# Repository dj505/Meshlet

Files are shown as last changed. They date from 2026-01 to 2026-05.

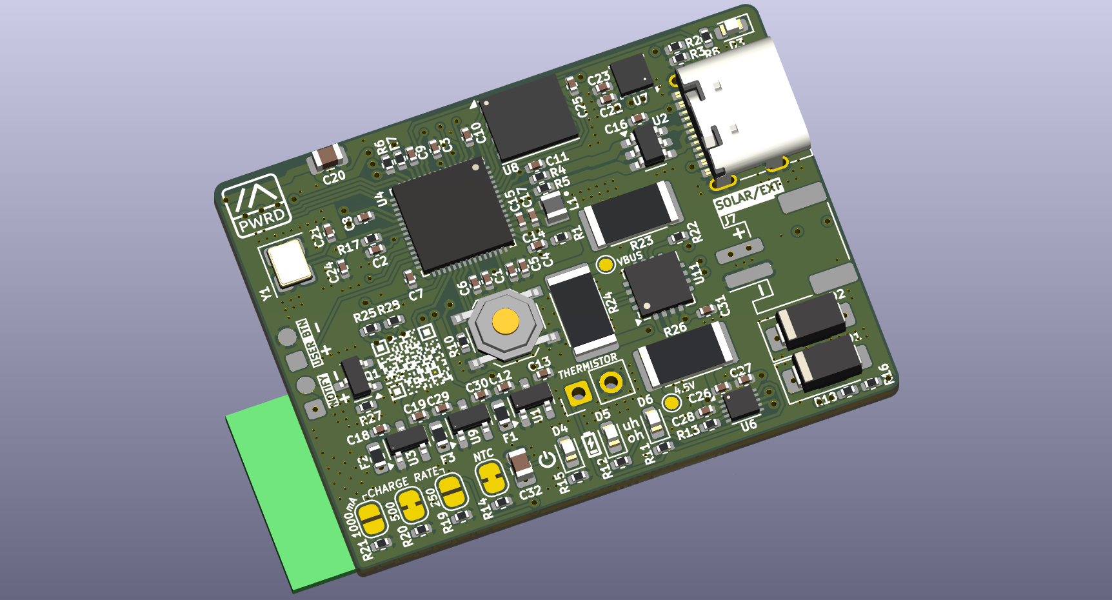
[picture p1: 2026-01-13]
docs/assets/1.png

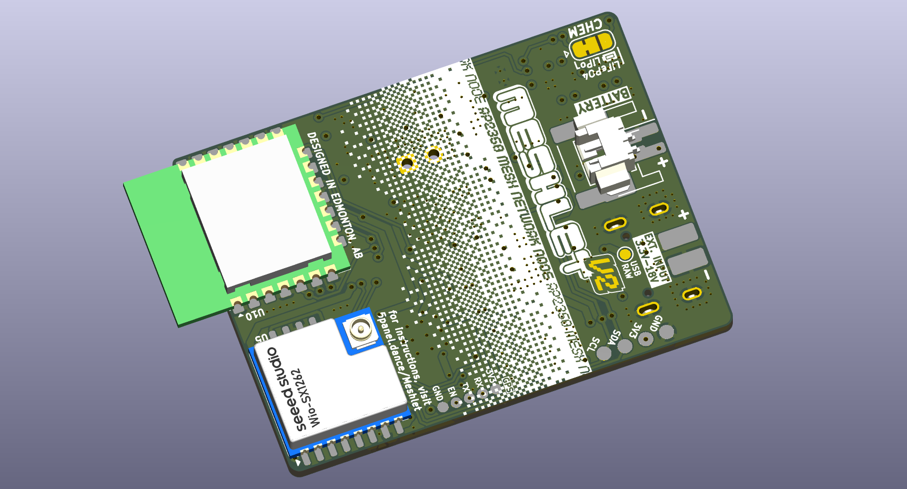
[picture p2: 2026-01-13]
docs/assets/2.png

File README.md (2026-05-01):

# [Meshlet V2](https://5panel.dance/Meshlet)

Meshlet is an open-source and feature-packed LoRa mesh network node, designed to be compatible (but not affiliated) with the Meshtastic® project. It's made to be deployed just about anywhere you want it to be - you can plug in a solar panel and set it up outside, turn it into a pocketable every-day-carry node, wire it up to your car as a mobile repeater, or even just leave it on a windowsill attached to a BBS script/Meshsense/etc. 

**Table of Contents**
1. [Features](#features)
2. [Project Sponsor](#project-sponsor)
3. [Real World Testing](#real-world-testing)
5. [Meshlet Docs](#meshlet-docs)

## Features
Features include, but are not limited to...
- USB C, with configurable charge rate limit (250mA, 500mA, 1A)
- LiPo/LiIon and LiFePo4 support
- ESD/TVS protection on the USB port
- Solar input (as well as constant DC input) from 3.3V to 18V, tolerant up to 25V
  - Flexible wiring methods, with dedicated JST PH footprints as well as pads to directly solder wires to!
  - Tested & working with as little as a cheap 80mm 5v solar panel, on an overcast Canadian winter day!
  - Unlike many boards that need a manual reset after too little sunlight drains the battery, the Meshlet should recover on its own!
- Smart power path management, thanks to the BQ25185. No need to worry about unnecessarily cycling the battery!
- JST 2.0 and Picoblade 1.5mm battery connector footprints, to hopefully fit whatever LiPos you've got laying around
- Low operating power, measuring as low as 2.8mA idle current draw (without WiFi)
- Active current/voltage monitoring and reporting on 3 channels over the mesh, via INA3221
  - Ch. 1: Battery
  - Ch. 2: USB & external power
  - Ch. 3: BQ25185 regulated battery output
- Up to 8MB onboard flash
- WIO-SX1262 LoRa radio
- BME280 temperature/humidity/barometric pressure sensor
- I2C expansion port
- Dedicated 3.3V regulators for all major components, each with its own self-resetting fuse, to ensure stable power
- "External notification" header for a MOSFET-driven 3.3V buzzer, LED, vibration motor, etc
- Raspberry Pi RM2 for optional WiFi (and Bluetooth, whenever the firmware supports it)
- Total footprint size of ~42*32mm, less than half the size of a credit card!

## Project Sponsor
This project is sponsored by [PCBWay](https://pcbway.com)! Absolutely massive thank you to them for helping make these projects possible for me.

If you're interested in DIY electronics, I'm sure you're familiar with the name. PCBWay is a manufacturing company specializing in circuit boards, but they also offer services for SMT assembly, CNC milling, 3D printing, sheet metal fabrication, and injection molding! They can manufacture all of the parts for your hobby project, in one convenient place, with fine-grained control over the entire manufacturing process.

I relied pretty heavily on their PCB manufacturing and SMT assembly services to get the final revision of the Meshlet project built & tested. In my past experience, their boards always come out beautiful and pretty near perfect, and these ones are no exception. Their engineers were in contact with me from start to finish, making sure that everything was correct and to spec throughout each step of the process. They sourced all of the parts based on the BOM I provided, ensured that each pick lined up with what I needed, and even sent confirmation photos before the assembly process to ensure that every part was placed & oriented properly. When I mistakenly selected two parts to fit a single footprint, they agreed with my request to ship me the extra parts that I had them order alongside the PCBs, for me to solder by hand if needed after I receive them!

Sponsors like this make a huge difference in allowing me to continue testing & iterating on projects like this one. Without this opportunity, it likely would have stopped at the first revision prototype! Thanks again to PCBWay for reaching out and organizing this opportunity. Please [check them out](https://pcbway.com), and definitely consider using their services for your next project! 

## Real World Testing
Meshlet has been tested in a variety of real-world use cases thus far, including...
- **Building side solar repeater:** An early Meshlet V2 revision (1.0) installed inside a weatherproof box, with a 5V solar panel and 3000mAh LiPo, in late winter conditions. Runs Meshtastic in CLIENT_BASE mode. Uptime as of writing is roughly a month, with zero resets or brownouts. Battery life has not dropped below 40%. Average draw is 28-32mA, plus an extra 8-12mA due to a secondary nRF52 MeshCore repeater node being powered via the 3v3 peripheral pins.
- **Cheap garden light repeater:** A latest revision Meshlet V2 (1.1) installed inside a cheap solar garden light from Home Depot. Solar panel has been wired directly to the solar input. Powered by two 1000mAh parallel LiFePO4 18500 batteries that came with the light. Has not yet dropped below 50% in 1 week of testing. Runs MeshCore, as a repeater.
- **Handheld unit:** An early revision Meshlet V2 (1.0) in a custom 3D printed case, with an I2C OLED and M5Stack CardKB soldered to the I2C breakout. Powered by a 3000mAh battery. Running Meshtastic. Has not yet undergone extensive testing, but showed promise with a battery life lasting at least 3 days with the CLIENT_MUTE role.
- **Bench testing:** Early revision Meshlet V2 (1.0) in the plastic case from a Heltec T114, powered by a recycled 1000mAh vape battery. Has undergone testing with several different solar panels (4V-7V), DC power supplies (5V-12V), charge rates, and I2C peripherals. Has been able to handle everything I've thrown at it so far. Survived having both a solar panel and a battery being plugged in with the incorrect polarity on separate occasions.

## Meshlet Docs
Assembly notes, firmware, and usage notes can all be found on [the Meshlet webpage.](https://www.5panel.dance/Meshlet/)

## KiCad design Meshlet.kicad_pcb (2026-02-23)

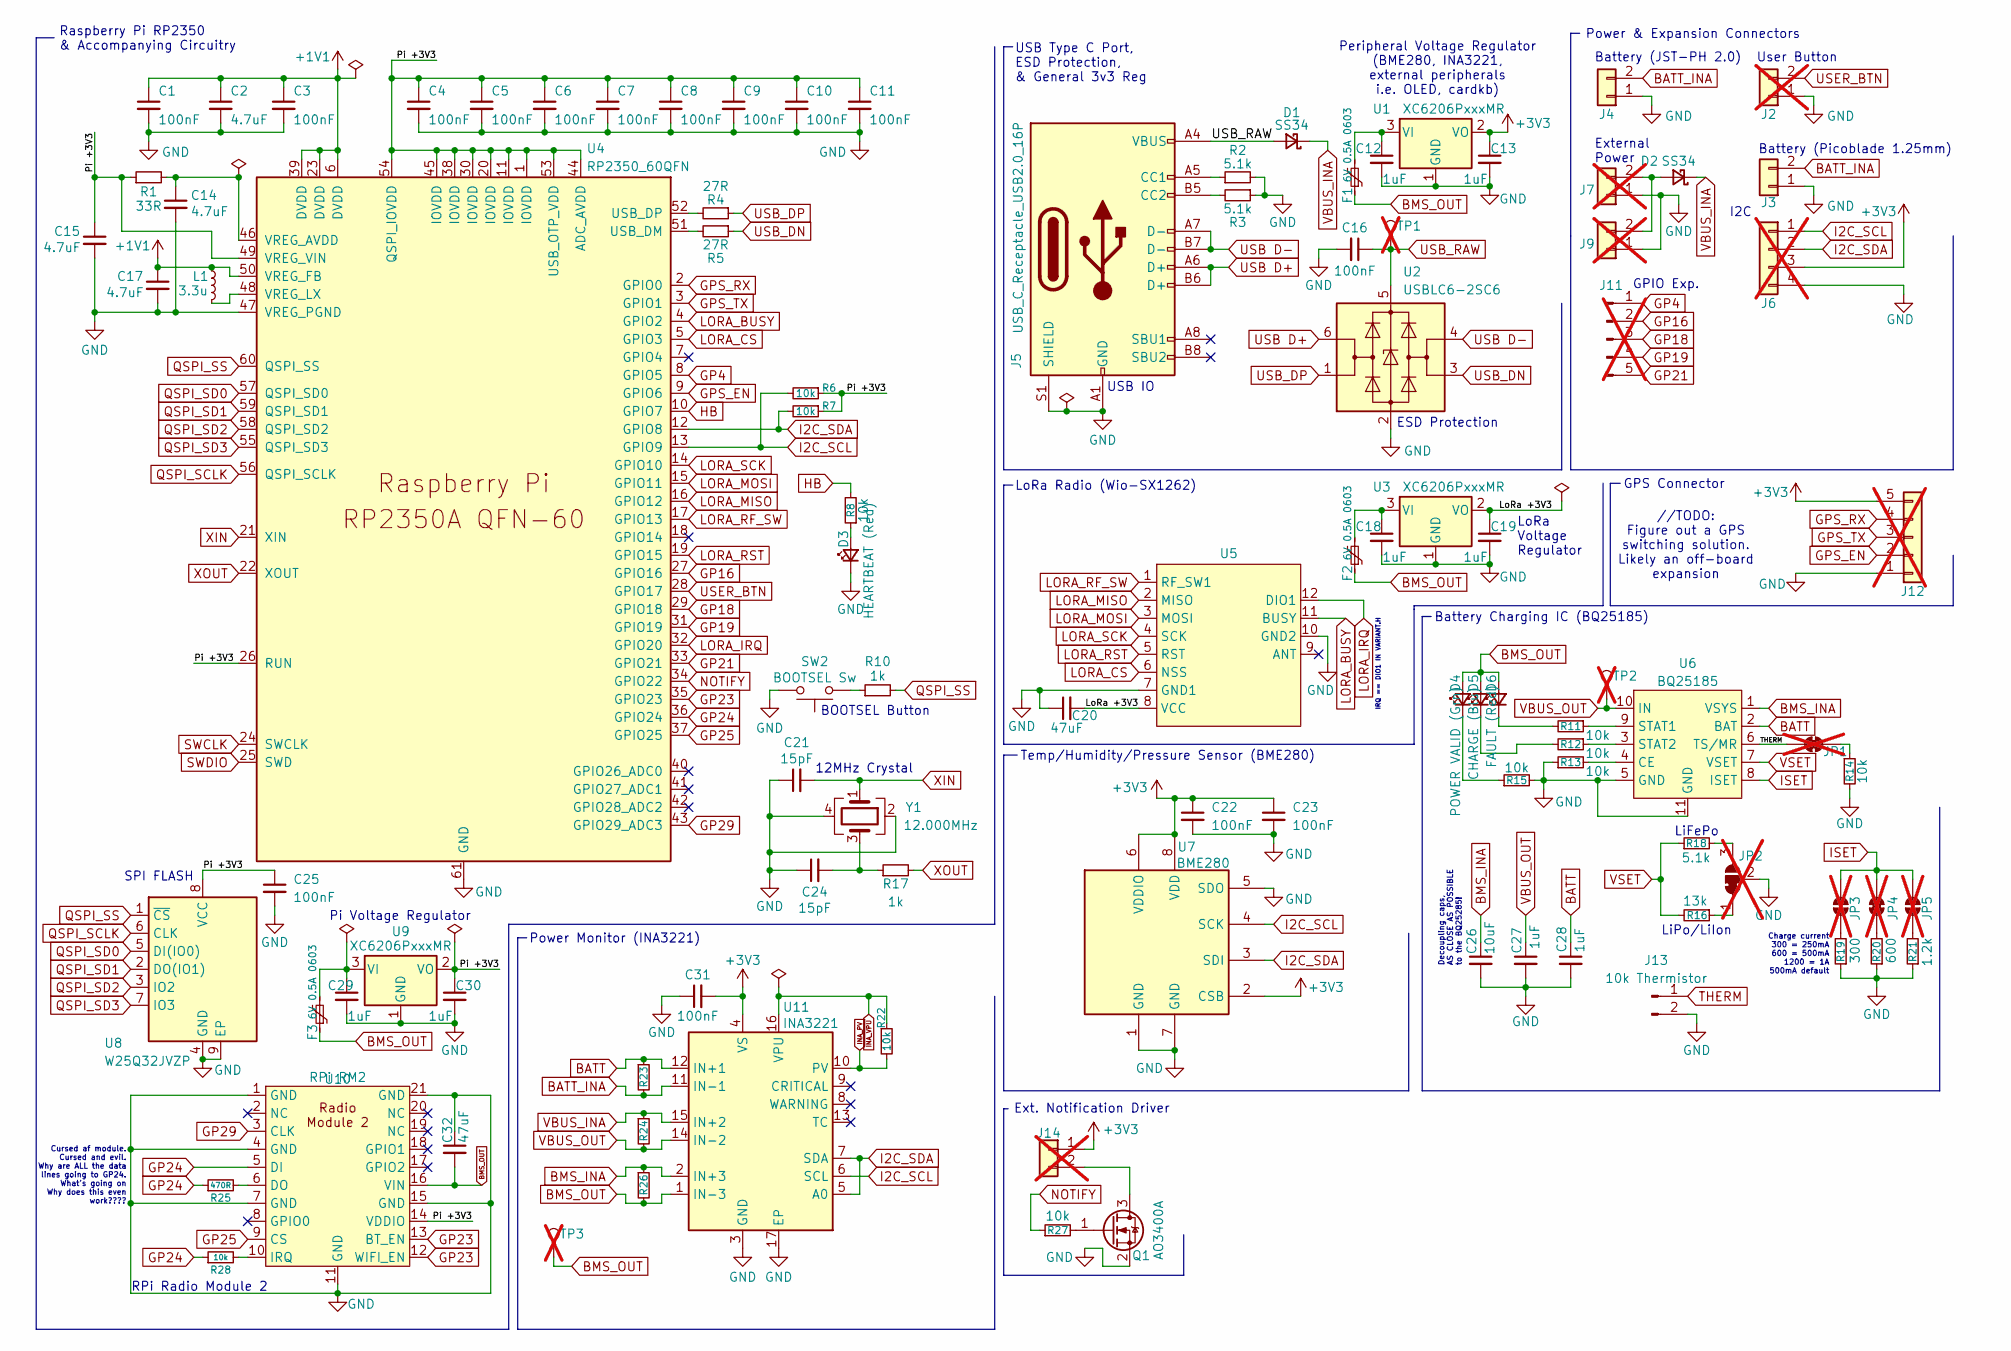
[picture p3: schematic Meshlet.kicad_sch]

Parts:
C1, C3, C4, C5, C6, C7, C8, C9, C10, C11, C16, C22, C23, C25, C31: 100nF; C_0402_1005Metric; LCSC C1525
C2, C14: 4.7uF; C_0402_1005Metric; LCSC C23733
C12, C13, C18, C19, C29, C30: 1uF; C_0402_1005Metric; LCSC C52923
C15, C17: 4.7uF; C_0402_1005Metric_small_pads; LCSC C23733
C20, C32: 47uF; C_0805_2012Metric; LCSC C16780
C21, C24: 15pF; C_0402_1005Metric; LCSC C1548
C26: 10uF; C_0402_1005Metric; LCSC C105226
C27, C28: 1uF; C_0402_1005Metric; LCSC C105226
D1, D2: SS34; D_SMA; LCSC C8678
D3: HEARTBEAT (Red); LED_0603_1608Metric; LCSC C2290
D4: POWER VALID (Grn); LED_0603_1608Metric; LCSC C2290
D5: CHARGE (Blu); LED_0603_1608Metric; LCSC C2290
D6: FAULT (Red); LED_0603_1608Metric; LCSC C2286
F1, F2, F3: 6V 0.5A 0603; Fuse_0603_1608Metric; LCSC C69679
J2: User Btn Header; PinHeader_1x02_P2.00mm_Vertical; not fitted
J3: Batt. Header (Picoblade 1.25); Molex_PicoBlade_53261-0271_1x02-1MP_P1.25mm_Horizontal; LCSC C177225
J4: Batt. Header (JST-PH 2.0); JST_PH_S2B-PH-SM4-TB_1x02-1MP_P2.00mm_Horizontal; LCSC C47647
J5: USB_C_Receptacle_USB2.0_16P; USB_C_Receptacle_G-Switch_GT-USB-7010ASV; LCSC C393939
J6: I2C Header; PinHeader_1x04_P2.00mm_Vertical; not fitted
J7: Ext. Power Header; JST_PH_S2B-PH-SM4-TB_1x02-1MP_P2.00mm_Horizontal; LCSC C27910; not fitted
J9: Ext. Power Header; PinHeader_1x02_P2.54mm_Vertical; not fitted
J11: GPIO Exp.; PinHeader_1x05_P2.00mm_Vertical; not fitted
J12: GPS Header; PinHeader_1x05_P1.27mm_Vertical; not fitted
J13: 10k Thermistor; PinHeader_1x02_P2.54mm_Vertical
J14: Ext. Notif. Header; PinHeader_1x02_P2.00mm_Vertical; not fitted
JP1: TS; SolderJumper-2_P1.3mm_Bridged_RoundedPad1.0x1.5mm; not fitted
JP2: Chemistry Select; SolderJumper-3_P1.3mm_Bridged12_RoundedPad1.0x1.5mm; not fitted
JP3: 250mA Charge; SolderJumper-2_P1.3mm_Open_RoundedPad1.0x1.5mm; not fitted
JP4: 500mA Charge; SolderJumper-2_P1.3mm_Bridged_RoundedPad1.0x1.5mm; not fitted
JP5: 1A Charge; SolderJumper-2_P1.3mm_Open_RoundedPad1.0x1.5mm; not fitted
L1: 3.3u; L_pol_2016; LCSC C42411119
Q1: AO3400A; SOT-23; LCSC C20917
R1: 33R; R_0402_1005Metric; LCSC C25105
R2, R3, R18: 5.1k; R_0402_1005Metric; LCSC C25905
R4, R5: 27R; R_0402_1005Metric; LCSC C25100
R6, R7, R8, R11, R12, R13, R14, R15, R22, R27, R28: 10k; R_0402_1005Metric; LCSC C25744
R10, R17: 1k; R_0402_1005Metric; LCSC C11702
R16: 13k; R_0402_1005Metric; LCSC C25754
R19: 300; R_0402_1005Metric; LCSC C25102
R20: 600; R_0402_1005Metric; LCSC C25126
R21: 1.2k; R_0402_1005Metric; LCSC C25862
R23, R24, R26: PA2512FKF7W0R01E; R_2512_6332Metric; LCSC C875838
R25: 470R; R_0402_1005Metric; LCSC C25117
SW2: BOOTSEL Sw; SW_Push_1P1T_XKB_TS-1187A; LCSC C318884
TP1, TP2, TP3: TestPoint; TestPoint_Pad_D1.0mm; not fitted
U1, U3, U9: XC6206PxxxMR; SOT-23-3; LCSC C5446
U2: USBLC6-2SC6; SOT-23-6; LCSC C2687116
U4: RP2350_60QFN; RP2350-QFN-60-1EP_7x7_P0.4mm_EP3.4x3.4mm_ThermalVias; LCSC C42411118
U5: Wio-SX1262
U6: BQ25185; Texas_DLH0010A_WSON-10-1EP_2.2x2mm_P0.4mm_EP0.9x1.5mm_Therm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; LCSC C19725033
U7: BME280; Bosch_LGA-8_2.5x2.5mm_P0.65mm_ClockwisePinNumbering; LCSC C92489
U8: W25Q32JVZP; WSON-8-1EP_6x5mm_P1.27mm_EP3.4x4.3mm; LCSC C2940197
U10: RPi RM2; Radio Module 2
U11: INA3221; Texas_RGV0016A_VQFN-16-1EP_4x4mm_P0.65mm_EP2.1x2.1mm; LCSC C181255
Y1: 12.000MHz; Crystal_SMD_3225-4Pin_3.2x2.5mm; LCSC C20625731

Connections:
+1V1: C1.1, C2.1, C3.1, C17.1, L1.1, U4.6 (DVDD), U4.23 (DVDD), U4.39 (DVDD), U4.50 (VREG_FB)
+3V3: C13.1, C22.1, C23.1, C31.2, J6.3, J12.5, J14.1, U1.2 (VO), U7.2 (CSB), U7.6 (VDDIO), U7.8 (VDD), U11.4 (VS)
/LoRa +3V3: C19.1, C20.2, U3.2 (VO), U5.8 (VCC)
/Pi +3V3: C4.1, C5.1, C6.1, C7.1, C8.1, C9.1, C10.1, C11.1, C15.1, C25.1, C30.1, R1.1, R6.1, R7.1, U4.1 (IOVDD), U4.11 (IOVDD), U4.20 (IOVDD), U4.26 (RUN), U4.30 (IOVDD), U4.38 (IOVDD), U4.44 (ADC_AVDD), U4.45 (IOVDD), U4.49 (VREG_VIN), U4.53 (USB_OTP_VDD), U4.54 (QSPI_IOVDD), U8.8 (VCC), U9.2 (VO), U10.14 (VDDIO)
BATT: C28.1, R23.1, U6.2 (BAT), U11.12 (IN+1)
BATT_INA: J3.2, J4.2, R23.2, U11.11 (IN-1)
BMS_INA: C26.1, R26.1, U6.1 (VSYS), U11.2 (IN+3)
BMS_OUT: C32.2, D4.2 (A), D5.2 (A), D6.2 (A), F1.1, F2.1, F3.1, R26.2, TP3.1, U10.16 (VIN), U11.1 (IN-3)
GND: C1.2, C2.2, C3.2, C4.2, C5.2, C6.2, C7.2, C8.2, C9.2, C10.2, C11.2, C12.2, C13.2, C14.2, C15.2, C16.2, C17.2, C18.2, C19.2, C20.1, C21.1, C22.2, C23.2, C24.1, C25.2, C26.2, C27.2, C28.2, C29.2, C30.2, C31.1, C32.1, D3.1 (K), J2.1, J3.1, J4.1, J5.A1 (GND), J5.A12 (GND), J5.B1 (GND), J5.B12 (GND), J5.S1 (SHIELD), J6.4, J7.1, J9.1, J12.1, J13.2, JP2.2 (C), Q1.2 (S), R2.2, R3.1, R13.1, R14.2, R15.2, R19.1, R20.1, R21.1, SW2.2, U1.1 (GND), U2.2 (GND), U3.1 (GND), U4.47 (VREG_PGND), U4.61 (GND), U5.7 (GND1), U5.10 (GND2), U6.5 (GND), U6.11 (GND), U7.1 (GND), U7.5 (SDO), U7.7 (GND), U8.4 (GND), U8.9 (EP), U9.1 (GND), U10.1 (GND), U10.4 (GND), U10.7 (GND), U10.11 (GND), U10.15 (GND), U10.21 (GND), U11.3 (GND), U11.17 (EP), Y1.2, Y1.4
GP4: J11.1, U4.8 (GPIO5)
GP16: J11.2, U4.27 (GPIO16)
GP18: J11.3, U4.29 (GPIO18)
GP19: J11.4, U4.31 (GPIO19)
GP21: J11.5, U4.33 (GPIO21)
GP23: U4.35 (GPIO23), U10.12 (WIFI_EN), U10.13 (BT_EN)
GP24: R25.1, R28.1, U4.36 (GPIO24), U10.5 (DI)
GP25: U4.37 (GPIO25), U10.9 (CS)
GP29: U4.43 (GPIO29_ADC3), U10.3 (CLK)
GPS_EN: J12.2, U4.9 (GPIO6)
GPS_RX: J12.4, U4.2 (GPIO0)
GPS_TX: J12.3, U4.3 (GPIO1)
HB: R8.2, U4.10 (GPIO7)
I2C_SCL: J6.1, R6.2, U4.13 (GPIO9), U7.4 (SCK), U11.6 (SCL)
I2C_SDA: J6.2, R7.2, U4.12 (GPIO8), U7.3 (SDI), U11.5 (A0), U11.7 (SDA)
INA_PV: R22.2, U11.10 (PV)
INA_VPU: R22.1, U11.16 (VPU)
ISET: JP3.2 (B), JP4.2 (B), JP5.2 (B), U6.8 (ISET)
LORA_BUSY: U4.4 (GPIO2), U5.11 (BUSY)
LORA_CS: U4.5 (GPIO3), U5.6 (NSS)
LORA_IRQ: U4.32 (GPIO20), U5.12 (DIO1)
LORA_MISO: U4.16 (GPIO12), U5.2 (MISO)
LORA_MOSI: U4.15 (GPIO11), U5.3 (MOSI)
LORA_RF_SW: U4.17 (GPIO13), U5.1 (RF_SW1)
LORA_RST: U4.19 (GPIO15), U5.5 (RST)
LORA_SCK: U4.14 (GPIO10), U5.4 (SCK)
NOTIFY: R27.1, U4.34 (GPIO22)
unnamed: C24.2, R17.1, Y1.3
unnamed: D2.2 (A), J7.2, J9.2
unnamed: D3.2 (A), R8.1
unnamed: D4.1 (K), R15.1
unnamed: D5.1 (K), R12.2
unnamed: D6.1 (K), R11.2
unnamed: J5.A5 (CC1), R2.1
unnamed: J5.B5 (CC2), R3.2
unnamed: J14.2, Q1.3 (D)
unnamed: JP1.2 (B), R14.1
unnamed: JP2.1 (A), R16.1
unnamed: JP2.3 (B), R18.2
unnamed: JP3.1 (A), R19.2
unnamed: JP4.1 (A), R20.2
unnamed: JP5.1 (A), R21.2
unnamed: Q1.1 (G), R27.2
unnamed: R10.1, SW2.1
unnamed: C12.1, F1.2, U1.3 (VI)
unnamed: C18.1, F2.2, U3.3 (VI)
unnamed: R5.2, U4.51 (USB_DM)
unnamed: R4.2, U4.52 (USB_DP)
unnamed: C14.1, R1.2, U4.46 (VREG_AVDD)
unnamed: L1.2, U4.48 (VREG_LX)
unnamed: R13.2, U6.4 (CE)
unnamed: R11.1, U6.9 (STAT1)
unnamed: R12.1, U6.3 (STAT2)
unnamed: C29.1, F3.2, U9.3 (VI)
unnamed: R25.2, U10.6 (DO)
unnamed: R28.2, U10.10 (IRQ)
QSPI_SCLK: U4.56 (QSPI_SCLK), U8.6 (CLK)
QSPI_SD0: U4.57 (QSPI_SD0), U8.5 (DI(IO0))
QSPI_SD1: U4.59 (QSPI_SD1), U8.2 (DO(IO1))
QSPI_SD2: U4.58 (QSPI_SD2), U8.3 (IO2)
QSPI_SD3: U4.55 (QSPI_SD3), U8.7 (IO3)
QSPI_SS: R10.2, U4.60 (QSPI_SS), U8.1 (~CS)
SWCLK: U4.24 (SWCLK)
SWDIO: U4.25 (SWD)
THERM: J13.1, JP1.1 (A), U6.6 (TS/MR)
USB D+: J5.A6 (D+), J5.B6 (D+), U2.6 (I/O1)
USB D-: J5.A7 (D-), J5.B7 (D-), U2.4 (I/O2)
USB_DN: R5.1, U2.3 (I/O2)
USB_DP: R4.1, U2.1 (I/O1)
USB_RAW: C16.1, D1.2 (A), J5.A4 (VBUS), J5.A9 (VBUS), J5.B4 (VBUS), J5.B9 (VBUS), TP1.1, U2.5 (VBUS)
USER_BTN: J2.2, U4.28 (GPIO17)
VBUS_INA: D1.1 (K), D2.1 (K), R24.1, U11.15 (IN+2)
VBUS_OUT: C27.1, R24.2, TP2.1, U6.10 (IN), U11.14 (IN-2)
VSET: R16.2, R18.1, U6.7 (VSET)
XIN: C21.2, U4.21 (XIN), Y1.1
XOUT: R17.2, U4.22 (XOUT)

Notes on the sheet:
Charge current 300 = 250mA 600 = 500mA 1200 = 1A 500mA default
I2C
LoRa Voltage Regulator
IRQ == DIO1 IN VARIANT.H
12MHz Crystal
LiFePo
Pi Voltage Regulator
SPI FLASH
Power Monitor (INA3221)
Cursed af module. Cursed and evil. Why are ALL the data lines going to GP24. What's going on Why does this even work????
Battery Charging IC (BQ25185)
Battery (JST-PH 2.0)
External Power
LoRa Radio (Wio-SX1262)
User Button
ESD Protection
Power & Expansion Connectors
Ext. Notification Driver
USB Type C Port, ESD Protection, & General 3v3 Reg
Raspberry Pi RP2350 & Accompanying Circuitry
Peripheral Voltage Regulator (BME280, INA3221, external peripherals i.e. OLED, cardkb)
//TODO: Figure out a GPS switching solution. Likely an off-board expansion
Temp/Humidity/Pressure Sensor (BME280)
GPIO Exp.
USB IO
Decoupling caps, AS CLOSE AS POSSIBLE to the BQ25285!
RPi Radio Module 2
LiPo/LiIon
Battery (Picoblade 1.25mm)
GPS Connector
BOOTSEL Button

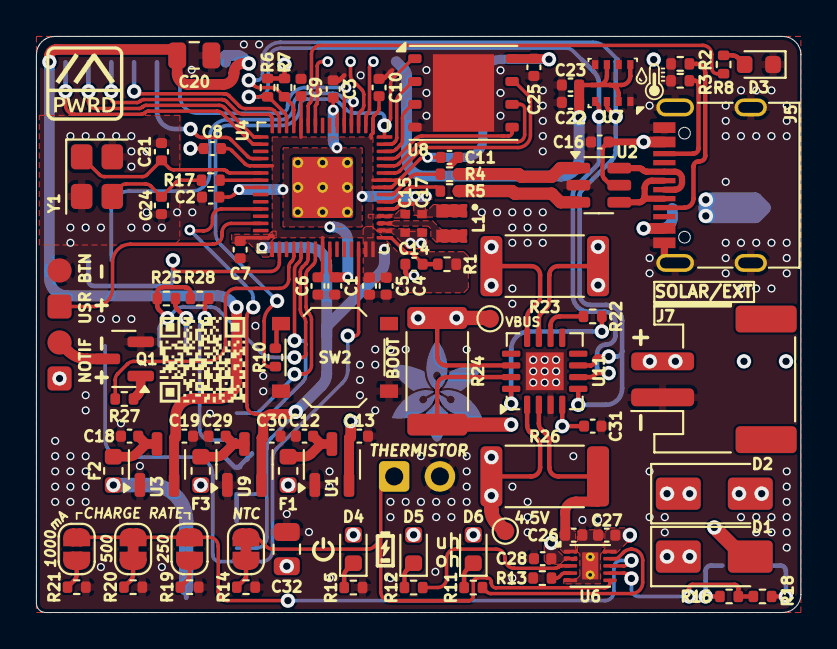
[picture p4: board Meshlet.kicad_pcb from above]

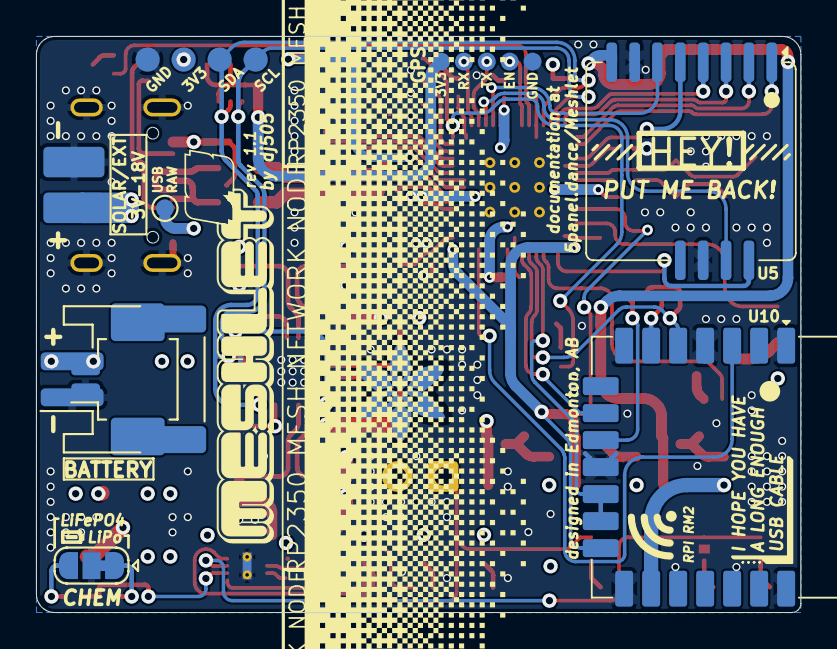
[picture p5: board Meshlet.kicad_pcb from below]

Board: 4 copper layers, 42.5 x 32.0 mm, 101 parts (9 on the bottom side), 78 nets.

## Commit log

2025-07-21 Initial commit - finished schematic
    [Meshlet.kicad_pcb, Meshlet.kicad_sch, RP2350_60QFN_minimal.kicad_sch]
2025-07-27 PCB routing like 99% done oops
    [Meshlet.kicad_pcb, Meshlet.kicad_sch]
2025-08-03 Custom Pi RM2 symbol/footprint, silkscreen gfx
    [Meshlet.kicad_pcb, Meshlet.kicad_sch]
2025-08-03 Tooling holes, silkscreen changes
    [Meshlet.kicad_pcb, Meshlet.kicad_sch]
2025-08-03 fix picoblade battery polarity hopefully 🤞
    [Meshlet.kicad_pcb, Meshlet.kicad_sch]
2025-08-03 Fixed exposed ground between jumper pads, yikes
    [Meshlet.kicad_pcb]
2025-08-04 appease the trademark gods
    [Meshlet.kicad_pcb]
2025-08-06 Fixed stemma port pin order, more touchups
    [Meshlet.kicad_pcb, Meshlet.kicad_sch]
2025-08-06 Ground fill thermal spoke bug workaround for RM2
    [Meshlet.kicad_pcb]
2025-08-07 Better thermal relief bug workaround?
    [Meshlet.kicad_pcb]
2025-08-14 Silkscreen changes, added BQ24074 output breakout
    [Meshlet.kicad_pcb, Meshlet.kicad_sch]
2025-12-29 Fixed several design flaws. More caps, more LDOs, etc
    [Meshlet.kicad_pcb, Meshlet.kicad_sch]
2026-01-03 Major changes to schematic
    Replace BQ24074 with BQ25185, remove extraneous passives, simplified several areas, add extra GPIO breakouts, reannotated schematic, etc.
    [Meshlet.kicad_pcb, Meshlet.kicad_sch]
2026-01-09 4 layer ver. complete!
    [Meshlet.kicad_pcb, Meshlet.kicad_sch]
2026-01-11 Small changes
    [Meshlet.kicad_pcb]
2026-01-11 silkscreen tweaks
    [Meshlet.kicad_pcb]
2026-01-12 Silkscreen tweaks, update docs
    [Meshlet.kicad_pcb]
2026-01-13 Add interactive BOM
    [Meshlet.kicad_pcb]
2026-01-13 Add GPS header
    [Meshlet.kicad_pcb, Meshlet.kicad_sch]
2026-01-13 GPS header labels
    [Meshlet.kicad_pcb]
2026-01-13 Add test points for power
    [Meshlet.kicad_pcb, Meshlet.kicad_sch]
2026-01-13 Trace tuning, silkscreen touch-ups, BOM touch-ups
    [Meshlet.kicad_pcb, Meshlet.kicad_sch]
2026-01-13 I knew something was missing. Lil thermometer icon
    [Meshlet.kicad_pcb]
2026-01-14 Trace and zone tune-ups
    [Meshlet.kicad_pcb]
2026-01-14 Rounded all of the traces on the top layer. For fun
    [Meshlet.kicad_pcb]
2026-01-15 Rounded traces on the back side too, updated ibom
    [Meshlet.kicad_pcb]
2026-01-16 Just in case commit before changing via stitching
    [Meshlet.kicad_pcb]
2026-01-16 Bigger vias. Less manufacturing fees. I hope
    [Meshlet.kicad_pcb]
2026-01-16 accidentally shorted the inner layers oops
    [Meshlet.kicad_pcb]
2026-02-23 Fix text sizes for production, fix batt chem label
    [Meshlet.kicad_pcb, Meshlet.kicad_sch]
2026-02-23 R16/R18 silkscreen labels swapped, fixed
    [Meshlet.kicad_pcb]
2026-02-23 Hopefully last little silkscreen fix
    [Meshlet.kicad_pcb]
2026-02-23 ibom updates
    [Meshlet.kicad_pcb, Meshlet.kicad_sch]
2026-02-23 Replaced C26-28 22uF with basic 1uF/10uF caps
    [Meshlet.kicad_sch]
2026-02-23 Clean up BOM & iBOM
    [Meshlet.kicad_pcb, Meshlet.kicad_sch]
2026-02-23 Silkscreen cleanup
    [Meshlet.kicad_pcb]
2026-02-24 Update docs
    [Meshlet.kicad_sch]
